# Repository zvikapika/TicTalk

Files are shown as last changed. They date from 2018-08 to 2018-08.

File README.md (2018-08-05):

# TicTalk
TicTalk is an object that connects to your google calendar and tracks meetings appearing on it.
During these meetings is gets activated automatically and collects and analyzes audio data of, currently, up to 4 participants.

Hardware consists of an ESP8266 dev board, a 32 pixel led ring, an analog multiplexter, 4  microphones and a 3d-printred enclosure.

The plumbing: Using IFTTT, 15 minutes prior to any meeting that is about to start, the ESP receives a notification via Blynk API. 
From that minute on, it  counts down the time until the meeting is about to start. Then, after signaling meeting start (via the rudimentary ultra-cheesy led effect), it collects audio samples and evaluates then in order to make an educated guess as to who is the chief speaker in the conversation in that moment. The result of this evaluation is displayed on the led ring via color and place coding: Every speaker, assumed to be sitting in front of a microphone, is assigned a color by the system. At the end of the meeting, the collected data - scoring per participant, according to the amount of time that person was found to be speaking, is uploaded to Google Sheets via IFTTT, for further logging and analysis.

The purpose of this device is to eventually have a tchnology that allows us to investigate human interaction during a meeting or conversation, as well as, perhaps, promote collaborative meetings where all participants are engaged, not only one dominant speaker. Such conversations, we suspect, are more creative, satisfying, and usefull than others, both on short and long term.

important: *** NO AUDIO IS RECORDED OR UPLOADED DURING THE OPERATION OF THIS DEVICE ***
 
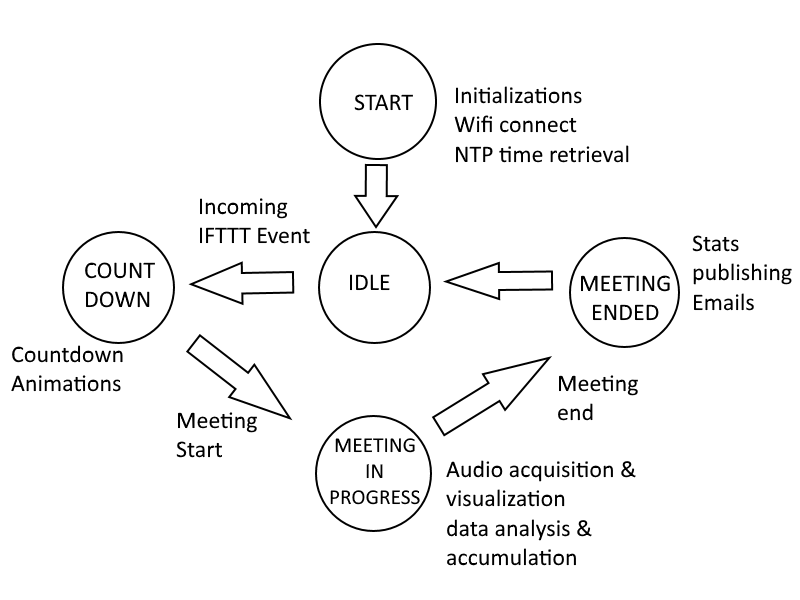
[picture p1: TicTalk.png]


TODO: 
add audio interpolation to support more than 4 participants sitting directly in front of their mics.
add quality of conversation metrics
act upon quality of conversation metrics, prolonging the meeting or other positive incentive

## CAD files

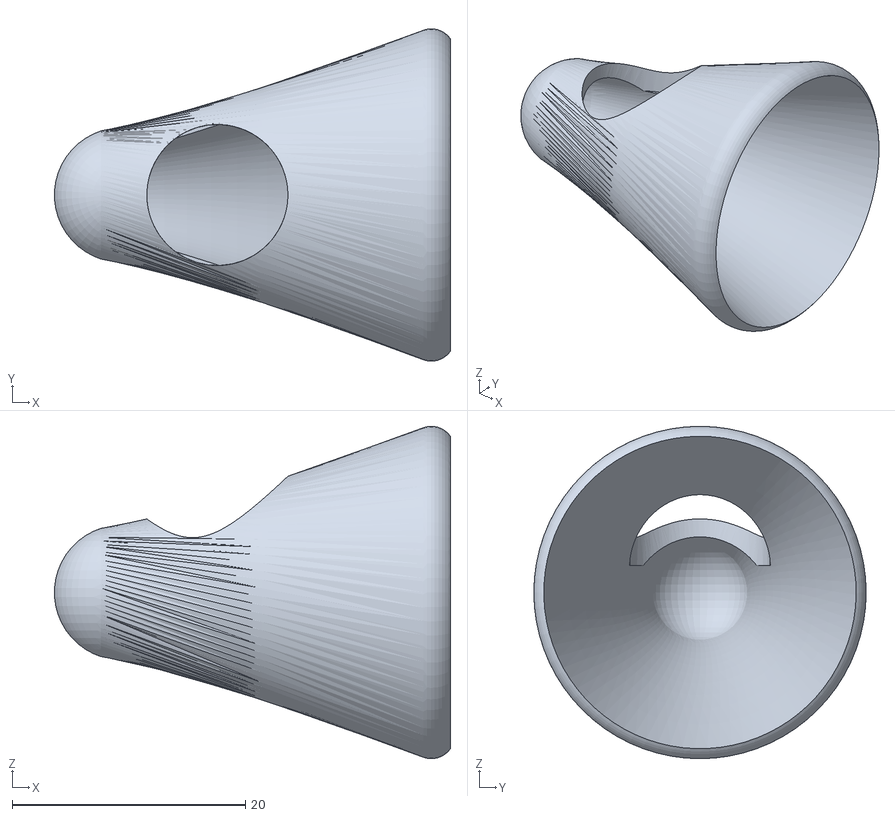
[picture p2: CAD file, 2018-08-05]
dev/cad/tik-tok01-Loft X 4.STL
34.0 x 28.5 x 28.5

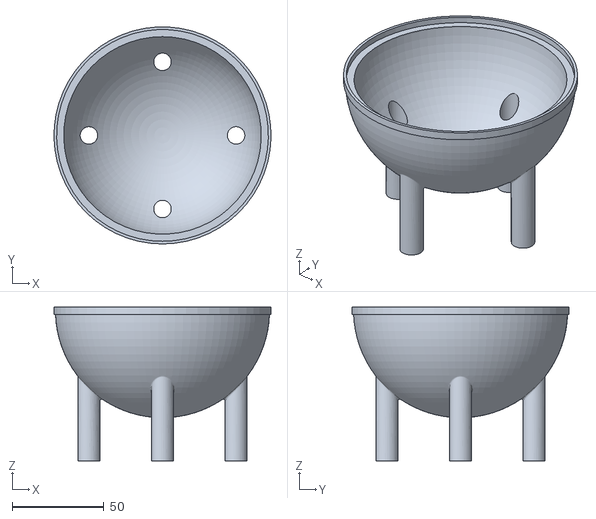
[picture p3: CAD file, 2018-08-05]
dev/cad/tik-tok01-Revolve3.STL
118.0 x 117.9 x 83.5

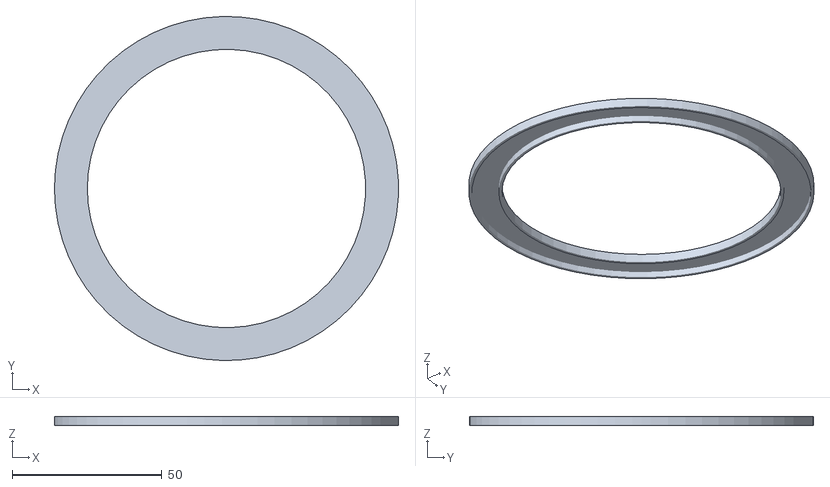
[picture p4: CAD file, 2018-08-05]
dev/cad/tik-tok01-Boss-Extrude1.STL
115.0 x 115.0 x 3.00

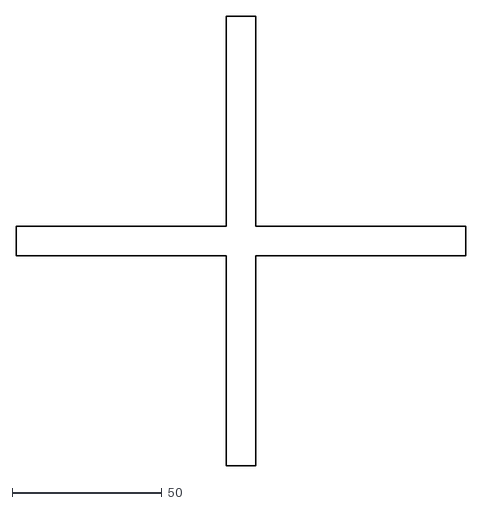
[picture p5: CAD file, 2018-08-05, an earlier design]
dev/cad/old/cross.dxf
150.0 x 150.0

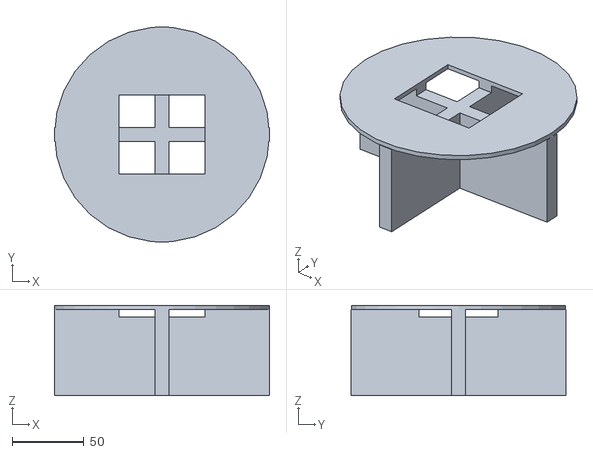
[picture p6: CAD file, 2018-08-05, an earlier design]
dev/cad/old/separator.stl
150.0 x 150.0 x 63.0

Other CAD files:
dev/cad/old/cross.scad
dev/cad/old/separator.scad

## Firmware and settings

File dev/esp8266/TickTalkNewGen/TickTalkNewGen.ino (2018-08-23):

#define BLYNK_PRINT Serial

#include <Adafruit_NeoPixel.h>
#include <Regexp.h>
#include <ESP8266WiFi.h>
#include <BlynkSimpleEsp8266.h>
#include <ESP8266WiFiMulti.h>

#include "neopixel.h"
#include "ntp_time.h"
#include "states.h"
#include "wifi_util.h"
#include "blynk_util.h"
#include "sensorama.h"
#include "ifttt_util.h"

#define IFTTT_TOKEN "pugCQ75bLBaZEZxrjEsIXvAzrqfhNJQKgFOSaOMGN4z"
#define IFTTT_EVENT_NAME "ticktalk_update"

int state;
int nextMeetingStartDay;
int nextMeetingStartMonth;
int nextMeetingStartYear;
int nextMeetingStartMinute;
int nextMeetingDuration;
int nextMeetingTriggerMinute;
char* colorNames[SENSOR_COUNT] = {
  "Red","Yellow","Green","Blue"
};
unsigned long meetingStartedTstamp = 0;

void setup() {
  Serial.begin(500000);
  state = STATE_STARTING;
}

void loop() {
  yield();
  // Serial.print("State: "); Serial.println(state);
  switch (state) {
    case STATE_STARTING:
      state = handleStarting();
      break;
    case STATE_IDLE:
      state = handleIdle();
      break;
    case STATE_TRIGGERED:
      state = handleTriggered();
      break;
    case STATE_COUNTDOWN:
      state = handleCountdown();
      break;
    case STATE_MEETING_START:
      state = handleMeetingStart();
      break;
    case STATE_MEETING_IN_PROGRESS:
      state = handleMeetingInProgress();
      break;
    case STATE_MEETING_END:
      state = handleMeetingEnd();
      break;
    default:
      Serial.println("UNHANDLED STATE. ABORTING");
      while (1) {
        yield();
      }
  }
  if (state != STATE_STARTING) {
    Blynk.run();
  }

}

int handleStarting() {
  neopixelInit();
  wifiConnect();
  ntptimeSetup();
  blynkSetup();
  rainbowCycle(1);
  colorWipe(0, 30);
  sensoramaSetup();
  return STATE_IDLE;
}

int handleIdle() {
  return STATE_IDLE;
}

int handleTriggered() {
  Serial.println("Meeting triggered!");
  struct tm * timeinfo = ntptimeGet();
  nextMeetingTriggerMinute = timeinfo->tm_min;
  return STATE_COUNTDOWN;
}

int handleCountdown() {
  int totalCountdownMinutes = getMinuteDiff(nextMeetingStartMinute, nextMeetingTriggerMinute);
  // Serial.print("totalCountdownMinutes="); Serial.println(totalCountdownMinutes);
  // handle hour cross i.e. when trigger time is on hour X and start time is x+1
  struct tm * timeinfo = ntptimeGet();
  // Serial.println(timeinfo->tm_min);
  // Serial.println(nextMeetingTriggerMinute);
  int countdownMinutesLapsed = getMinuteDiff(timeinfo->tm_min, nextMeetingTriggerMinute);
  // Serial.print("countdownMinutesLapsed="); Serial.println(countdownMinutesLapsed);
  int pixelCount = map(countdownMinutesLapsed, 0, totalCountdownMinutes, 1, strip.numPixels());
  // Serial.print("pixelCount="); Serial.println(pixelCount);
  neopixelFadeInOut(pixelCount, strip.Color(0,255,0));
  if (timeinfo->tm_min != nextMeetingStartMinute) {
    return STATE_COUNTDOWN;
  }
  else {
    return STATE_MEETING_START;
  }
}

int handleMeetingStart() {
  Serial.println("Meeting started!");
  rainbowCycle(1);
  colorWipe(0, 30);
  sensoramaReset();
  meetingStartedTstamp = millis();
  return STATE_MEETING_IN_PROGRESS;
}

int handleMeetingInProgress() {
  sensoramaUpdate();
  if((millis() - meetingStartedTstamp)/1000/60 < nextMeetingDuration) {
    return STATE_MEETING_IN_PROGRESS;
  }
  else return STATE_MEETING_END;
}

char stats[64];

int handleMeetingEnd() {
  Serial.println("Meeting ended!");
  Serial.println("Final Stats\n===========");
  String param = "";
  for(int i = 0; i < 4; ++i) {
    // >>> remove me! only for testing
    sensorLongTermRecords[i] = random(1, 1000);
    Serial.print(colorNames[i]); Serial.print(":"); Serial.println(sensorLongTermRecords[i]);
    param += sensorLongTermRecords[i];
    if(i < 3) param += ",";
  }
  param.toCharArray(stats, min(int(param.length()), 64));
  ifttt_trigger(IFTTT_EVENT_NAME, IFTTT_TOKEN, stats, NULL, NULL);
  for(int i = 0; i < 10; ++i) {
    neopixelTheaterChase(Wheel(i * 25), 1);
    Blynk.run();
  }
  return STATE_IDLE;
}


void onAppointmentTriggered(int startDay, int startMonth, int startYear, int startHour, int startMinute, int endHour, int endMinute, int duration) {
  Serial.println("NEW SCHEDULE");
  Serial.print("startDay=");    Serial.println(startDay);
  Serial.print("startMonth=");  Serial.println(startMonth);
  Serial.print("startYear=");   Serial.println(startYear);
  Serial.print("startHour="); Serial.println( startHour);
  Serial.print("startMinute="); Serial.println( startMinute);
  Serial.print("endHour=");     Serial.println(endHour);
  Serial.print("endMinute=");   Serial.println(endMinute);
  Serial.print("appointment duration(min): "); Serial.println(duration);
  nextMeetingStartDay = startDay;
  nextMeetingStartMonth = startMonth;
  nextMeetingStartYear = startYear;
  nextMeetingStartMinute = startMinute;
  nextMeetingDuration = duration;
  state = STATE_TRIGGERED;
}

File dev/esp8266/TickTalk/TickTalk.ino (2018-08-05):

#define BLYNK_PRINT Serial

#include <Adafruit_NeoPixel.h>
#include <Regexp.h>
#include <ESP8266WiFi.h>
#include <BlynkSimpleEsp8266.h>
#include <ESP8266WiFiMulti.h>

#include "neopixel.h"
#include "ntp_time.h"
#include "states.h"
#include "wifi_util.h"
#include "blynk_util.h"


int state;

void setup() {
  Serial.begin(115200);
  state = STATE_START;
}

void loop() {
  switch (state) {
    case STATE_START:
      state = handleStart();
      break;
    case STATE_IDLE:
      state = handleIdle();
      break;
    case STATE_AWAITING_MEETING_START:
      state = handleAwaitingMeetingStart();
      break;
    case STATE_MEETING_IN_PROGRESS:
      state = handleMeetingInProgress();
      break;
    case STATE_MEETING_ENDED:
      state = handleMeetingEnded();
      break;
  }
}

int handleStart() {
  neopixelInit();
  wifiConnect();
  ntptimeSetup();
  blynkSetup();
  rainbowCycle(1);
  colorWipe(0, 15);
  return STATE_IDLE;
}

int handleIdle() {
  return STATE_IDLE;
}

int handleAwaitingMeetingStart() {
  return STATE_AWAITING_MEETING_START;
}

int handleMeetingInProgress() {
  return STATE_MEETING_IN_PROGRESS;
}

int handleMeetingEnded() {
  return STATE_MEETING_ENDED;
}

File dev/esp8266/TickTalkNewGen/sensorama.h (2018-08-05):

#define SENSOR_COUNT 4
#define SAMPLE_INTERVAL_MS 4
#define RUNTIME_SAMPLE_COUNT 20
#define BASELINE_SAMPLE_COUNT 500
#define LIGHT_THRESHOLD 10
#define SOOTHING_FACTOR 25

const int channelControlPins[] = {D7, D6, D5, D0};
const int enablePin = D8;
const int inputPin = A0;

// red, yellow, green, blue
const float factor[SENSOR_COUNT] = {1.2, 1.05, 0.9, 1.15};
long sensorLongTermRecords[SENSOR_COUNT] = {0};

int sampleCounter = 0;

extern "C" {
#include "user_interface.h"
}

os_timer_t myTimer;
volatile boolean dataAvailable;
volatile boolean overflowDetected;

int inputs[SENSOR_COUNT] = {0,0,0,0};
long acc[SENSOR_COUNT] = {0,0,0,0};
long secondOrderAcc[SENSOR_COUNT] = {0,0,0,0};
long baselines[SENSOR_COUNT] = {0};
int startInput = 12;
int endInput = 15;
int ledsPerSensor;

void setInputChannel(int whichChannel) {
  for (int inputPin = 0; inputPin < 4; inputPin++) {
    int pinState = bitRead(whichChannel, inputPin);
    digitalWrite(channelControlPins[inputPin], pinState);
  }
}

void collect() {
  int i = 0;
  for (int muxChannel = startInput; muxChannel <= endInput; muxChannel++) {
    setInputChannel(muxChannel);
    inputs[i++] = analogRead(inputPin);
  }
}

void timerCallback(void *pArg) {
  collect();
  dataAvailable = true;
}

void user_init(void) {
  os_timer_setfn(&myTimer, timerCallback, NULL);
  os_timer_arm(&myTimer, SAMPLE_INTERVAL_MS, true);
}

void updateCounters() {
  for (int i = 0; i < SENSOR_COUNT; ++i) {
    // Serial.print(acc[i]); Serial.print(' ');
    acc[i] = (acc[i] / RUNTIME_SAMPLE_COUNT);
    secondOrderAcc[i] += (acc[i] * factor[i]);
    secondOrderAcc[i] -= SOOTHING_FACTOR;
    if(secondOrderAcc[i] < 0) secondOrderAcc[i] = 0;
    // Serial.print(acc[i]); Serial.print(' ');
    Serial.print(secondOrderAcc[i]); Serial.print(' ');
  }
  Serial.println();
}

long getColor(int sensorIdx, long volume) {
  switch (sensorIdx) {
    case 0:
      return strip.Color(volume, 0, 0);
      break;
    case 1:
      return strip.Color(volume,  volume, 0);
      break;
    case 2:
      return strip.Color(0, volume, 0);
      break;
    case 3:
      return strip.Color(0, 0, volume);
      break;
  }
}

void updateLeds() {
  long record = -1;
  int recordIdx = -1;
  for (int i = 0; i < SENSOR_COUNT; ++i) {
    if (secondOrderAcc[i] > LIGHT_THRESHOLD && secondOrderAcc[i] > record) {
      record = secondOrderAcc[i];
      recordIdx = i;
    }
  }
  if(record > 255) {
    int substract = record-255;
    for (int i = 0; i < SENSOR_COUNT; ++i) {
      secondOrderAcc[i] -= substract;
    }
    record -= substract;
  }

  for (int i = 0; i < strip.numPixels(); ++i) {
    strip.setPixelColor(i, 0);
  }
  if (record > 0) {
    long col = getColor(recordIdx, constrain(record, 0, 255));
    sensorLongTermRecords[recordIdx]++;
    for (int p = recordIdx * ledsPerSensor ; p < (recordIdx + 1) * ledsPerSensor; ++p) {
      strip.setPixelColor(p, col);
    }
  }
  strip.show();
}

void sensoramaCalibrate() {
  Serial.println("calibrating sensors...");
  for (int s = 0; s < BASELINE_SAMPLE_COUNT; ++s) {
    collect();
    for (int i = 0; i < SENSOR_COUNT; ++i) {
      acc[i] += inputs[i];
    }
  }
  Serial.println("sensor baselines:");
  for (int i = 0; i < SENSOR_COUNT; ++i) {
    baselines[i] = acc[i] / BASELINE_SAMPLE_COUNT;
    Serial.print(baselines[i]); Serial.print(' ');
    acc[i] = 0;
  }
  Serial.println();
  
}

void sensoramaSetup() {
  // WiFi.mode(WIFI_OFF);
  pinMode(enablePin, OUTPUT);
  digitalWrite(enablePin, LOW); // 4067 is active LOW
  for (int i = 0; i < 4; ++i) {
    pinMode(channelControlPins[i], OUTPUT);
  }
  sensoramaCalibrate();
  user_init();
  ledsPerSensor = (strip.numPixels() / SENSOR_COUNT);
}

void sensoramaReset() {
  for(int i = 0; i < SENSOR_COUNT; ++i) {
    sensorLongTermRecords[i] = 0;
  }
  // sensoramaCalibrate(); // needed?
}

void sensoramaUpdate() {
  if (dataAvailable) {
    for (int i = 0; i < SENSOR_COUNT; ++i) {
      acc[i] += (abs(inputs[i] - baselines[i]));
    }
    sampleCounter++;
    if (sampleCounter == RUNTIME_SAMPLE_COUNT) {
      updateCounters();
      updateLeds();
      sampleCounter = 0;
      for (int i = 0; i < SENSOR_COUNT; ++i) {
        acc[i] = 0;
      }
    }
    dataAvailable = false;
  }
}
